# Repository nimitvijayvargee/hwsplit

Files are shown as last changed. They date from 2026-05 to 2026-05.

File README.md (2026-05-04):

# hwsplit
handwired split keyboard with spare parts!

I made this for fun, and it is in NO WAY a functioning keyboard layout you may want to use. The function row does not work, and the backtick/tilde are also not present. There are probably going to be hundreds of flaws.

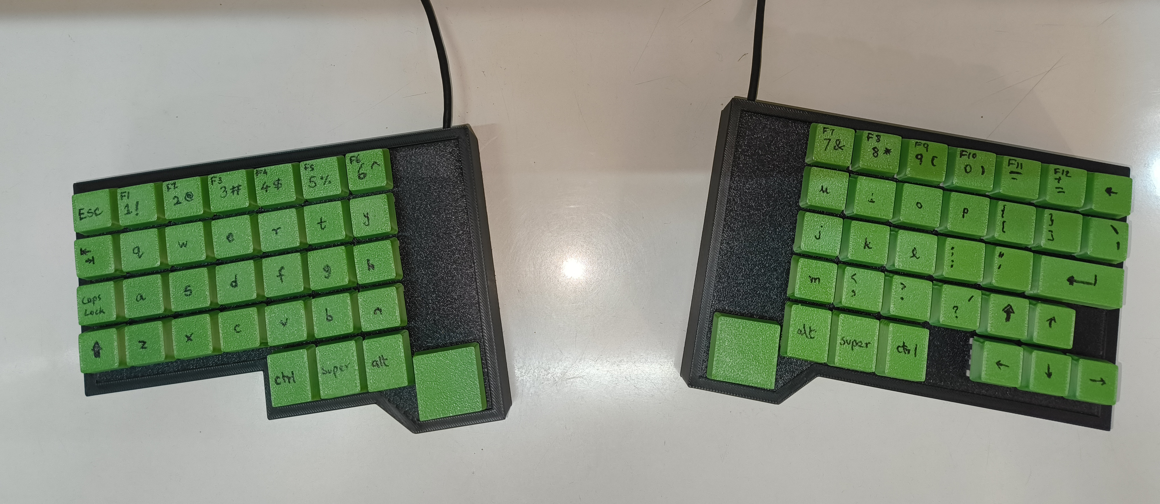
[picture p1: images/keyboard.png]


## Assembly Instructions
First of all, no idea why you'd EVER want to assembly one of these.
To begin, you must print the plates for both sides of the keyboard. I was able to do this in ~1.5 hours on my A1 in a single print. Pop your switches of choice through and wire up all the columns together. To make it easy, use solid core wire, enameled copper wire or a thin copper rod. Then, insulate the intersection points with the rows (I used masking tape) and connect the columns together. Make sure that the diodes point from the row to the switch (and subsequently to the column). Here's a sanity check for your matrix in KLE.
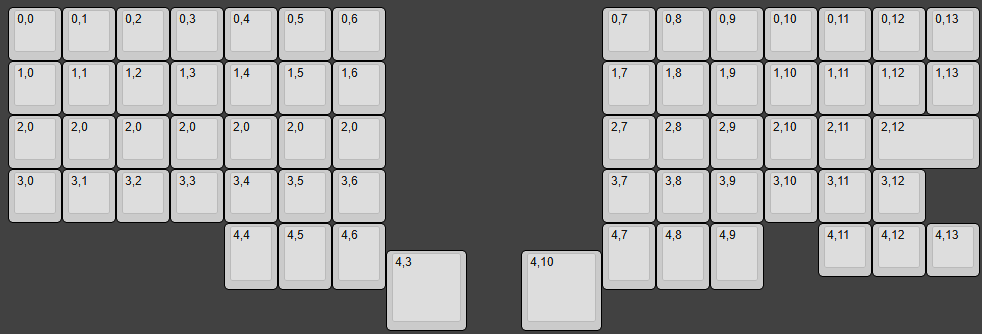
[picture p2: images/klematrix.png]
KLE matrix


Solder your wires to the Microcontroller (Pico). 

On the left:
  - Rows 0 to 4 -> GP0 to GP4
  - Columns 0 to 6 -> GP11 to GP5 (Backwards)

On the right:
  - Rows 0 to 4 -> GP0 to GP4
  - Columns 7 to 13 -> GP5 to GP11 (Forwards)

Flash your code by holding BOOTSEL on the pico while plugging it into your computer. Paste corresponding `.uf2` firmware files into the new `RPI-RP2` drive on your computer. Keyboard should automatically restart and start working.

Try using Vial's matrix tester to validate your matrix using the app (https://get.vial.today/) or on the web (https://vial.rocks/). Vial on the web needs a WebHID compatible browser. This includes almost all desktop versions of chromium (Edge, Arc, Chrome, etc.).

You can then set your keys to whatever you want!

If you need visual help, you may find some images in my [Journal](JOURNAL.md),
## Keycaps Needed
You will need 56x 1u keycaps, 1x 2u keycap and 6x 1.25u keycaps. The spacebar (or spaceblocks) are 2x (1.5u x 1.5u) square keycaps. These are not available anywhere to my knowledge. 

I printed all my keycaps, so it may be wise to do so.

## Overall BOM
- Soldering equipment (Iron, Solder and maybe flux)
- Solid Core copper wire / Thin Copper Rods / Enameled Copper Wire (Columns)
- Tape (any kind, I used masking/painter's tape)
- Switches (MX style, or anything that fits on an 19.05mm grid with 18mm cutouts).
- Diodes (1N4148)
- Case and Plate (I 3D printed these)
- 2x Raspberry Pi Picos
- 2x Micro USB-B Cables
- Keycaps (See above section)

Using switches from an old keyboard, the overall cost ran me about $13. I spent $5 on the wire, a little over $1 on the diodes and around $7 on the Picos.
Filament is not included in the cost, although I presume it did not take more than 500g of my daily PLA.

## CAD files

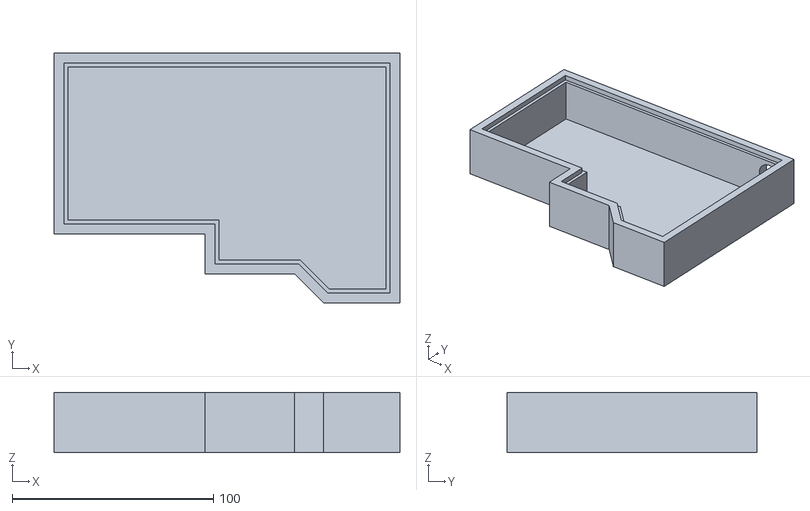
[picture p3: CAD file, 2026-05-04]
3dp/left_case.stl
172.1 x 124.3 x 30.0

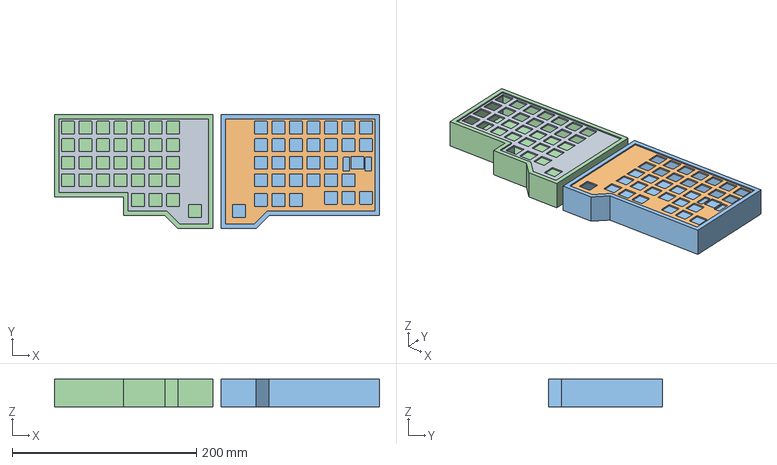
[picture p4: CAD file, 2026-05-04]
cad/hwsplit.step
352.9 x 124.3 x 30.0 mm

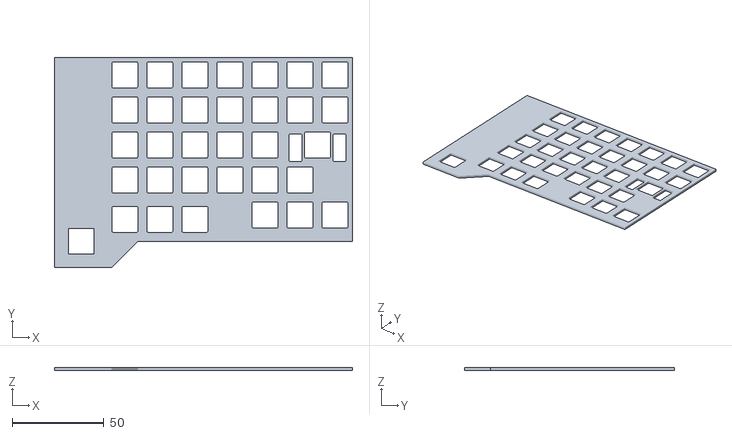
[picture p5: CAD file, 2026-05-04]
3dp/right_plate.stl
162.1 x 114.3 x 1.60

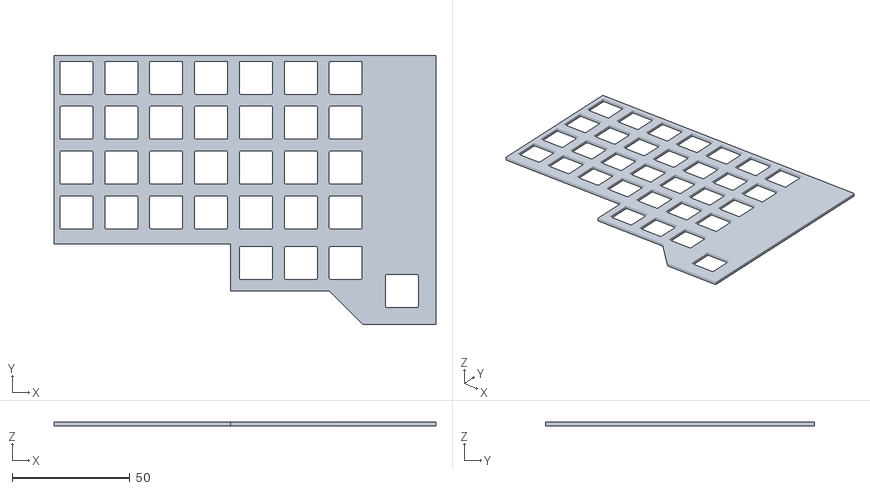
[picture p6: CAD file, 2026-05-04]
3dp/left_plate.stl
162.1 x 114.3 x 1.60

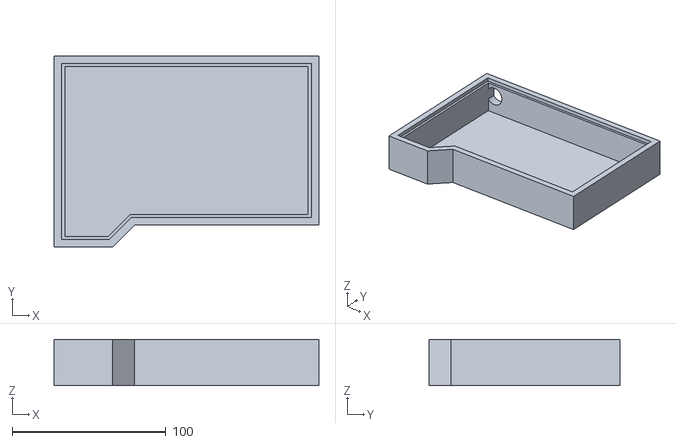
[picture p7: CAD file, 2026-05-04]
3dp/right_case.stl
172.1 x 124.3 x 30.0

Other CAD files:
cad/hwsplit.f3d

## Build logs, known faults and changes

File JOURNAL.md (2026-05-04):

# Journal
This is a journal log of all the work put into this project :) 
Use this while designing your keyboard if you want! Take everything with a mountain of salt, I messed up a lot of stuff

## Session 1
Time Spent: 45 Minutes

So I first started designing my keyboard using Keyboard Layout Editor. I took a bunch of inspiration from existing olkbs and split keyboards, and ended up on a decent looking layout! It had basically all I needed, and it looked quite straight forward. All the keycaps are readily available, except maybe the spacebars (which are actually 2 big 1.5u squares).
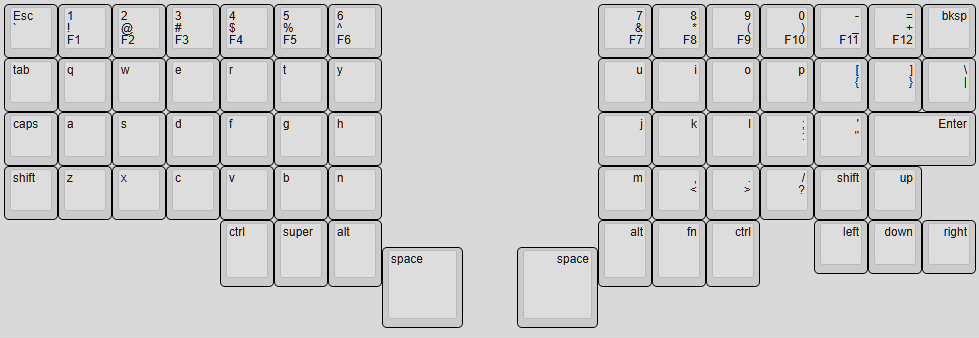
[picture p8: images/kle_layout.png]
KLE Layout


I moved the layout to ai03's Plate Generator tool (which is honestly such a good tool, wow); used the default settings and exported a DXF for my plate. I brought that plate into Fusion and extruded it 1.6mm and sent it to my printer. It's important that you make sure your printer can handle the dimensional accuracy. I used a 0.12mm layer height and a 0.4mm nozzle with mostly default settings on my Bambu Lab A1.
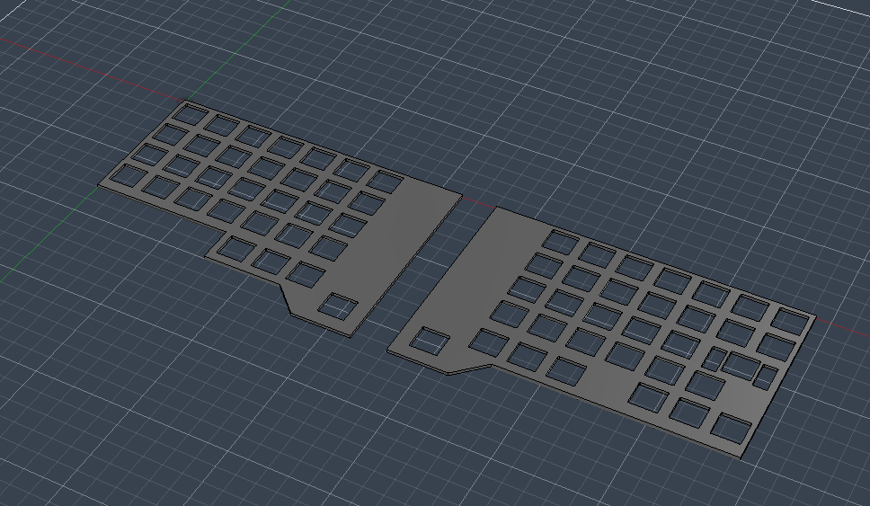
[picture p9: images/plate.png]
Plate

While the printer was printing, I also checked which parts I had and which parts I needed, and bought some diodes and solid core wire from an electronics store set to arrive on the same day.

## Session 2
Time Spent: 3 Hours

Around the time the plates finished printing, the parts also arrived! I used some spare switches from a 4 year old keyboard I had, and popped them into the plate where needed. I stripped the copper wires to solder the columns, and then insulated it with tape to solder diodes. It was really really shoddy on my first attempt. I also couldn't get the stabilizer in twt. Eventually, I finished soldering the first half and soldered some dupont connectors directly to the rows/columns quite easily. They did come off a lot, and my soldering could've been better.
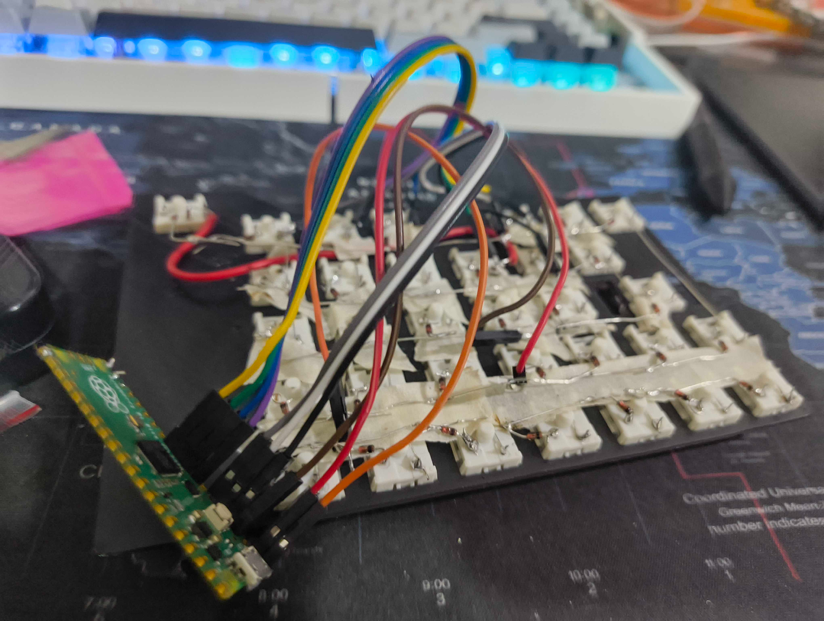
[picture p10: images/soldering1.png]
soldering 1


The thing with soldering for handwired keyboards is that it's extremely repepetive. It's easy to find yourself in a monotonous rhythym just as it is to find yourself in a flowstate.

After this, I took a small break and came back after 20 minutes to continue the other half.

## Session 3
Time Spent: 3 Hours

Armed with the new knowledge and skill on how to handwire keyboards, I started the left side of the keyboard!
I first added all of the columns, because that was the easy part. I added a small wire connecting to the space-square since it was quite straightforward.
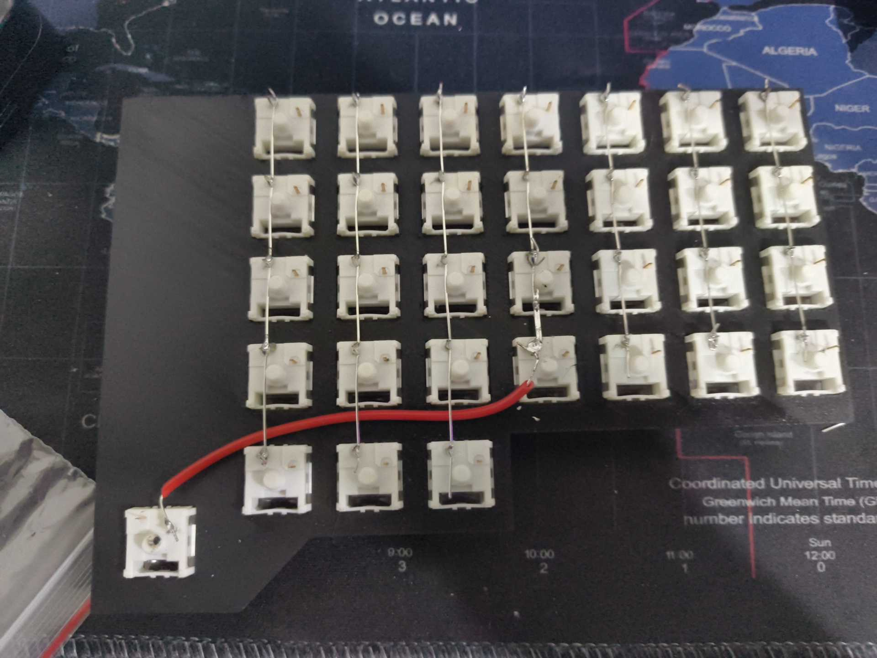
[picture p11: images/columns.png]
columns yay

After this, I added some tape to the parts between the switches to prevent shorting the columns and rows, and started soldering the diodes
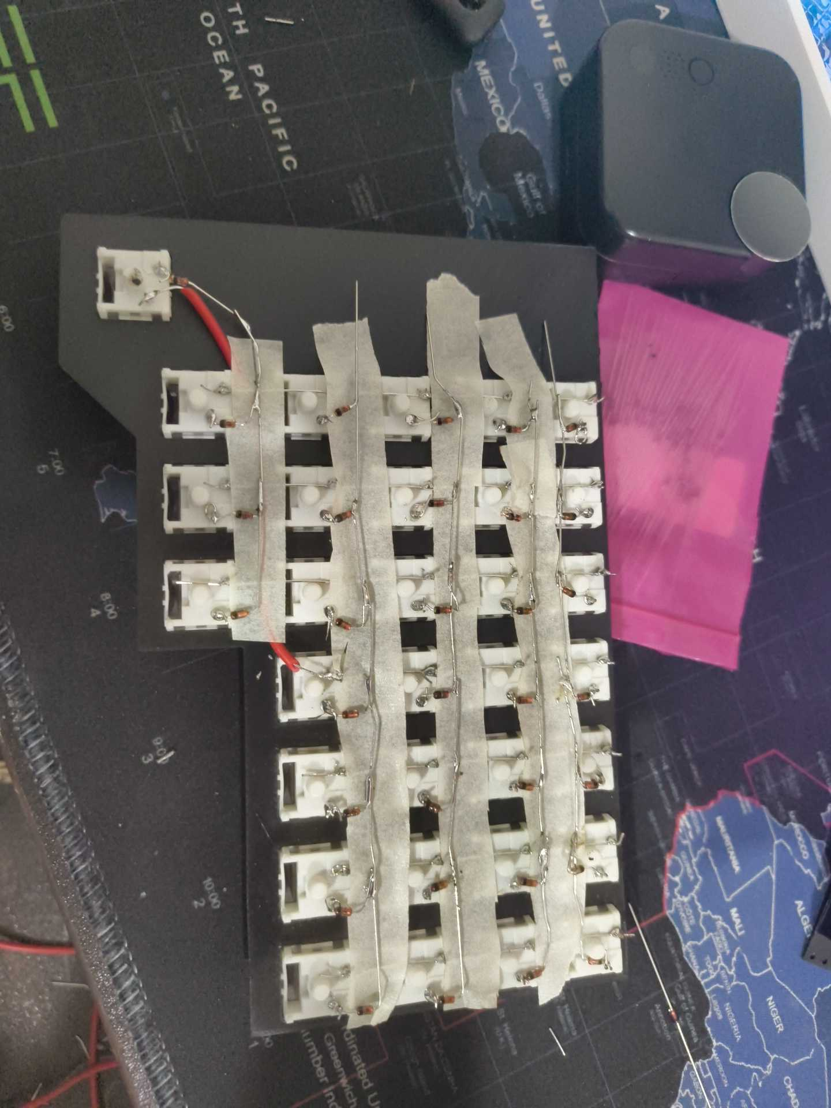
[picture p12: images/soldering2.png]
soldering 2

After finishing this thing, I quickly designed a small case and printed it. However, it wsa too shallow. I printed a deeper one and let that run overnight, and it kind of fit. But once I connected the USB cable, it didn't :(
Here's a picture of the case I printed in the morning!
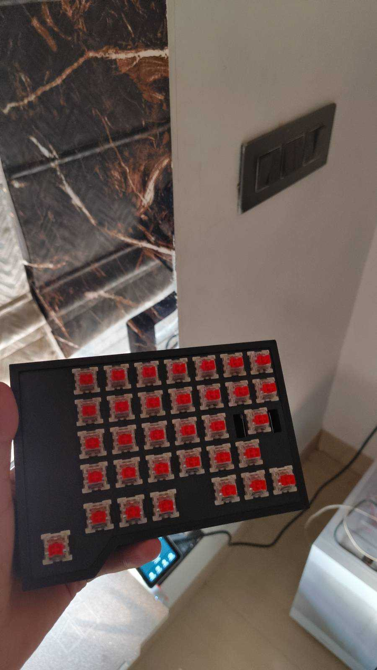
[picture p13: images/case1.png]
case


## Session 4
Time Spent: 2 Hours

I took the time to deepen out the cases 4mm more so that I have more headroom for the pico to be inside. I made a quick QMK firmware to see how it works, and spent the next hour reading docs and trying to find out how to do split keyboards that follow my mirrored matrix. I couldn't find that many resources, so I might just write my own code later, but I did somehow get it to show up in Vial?
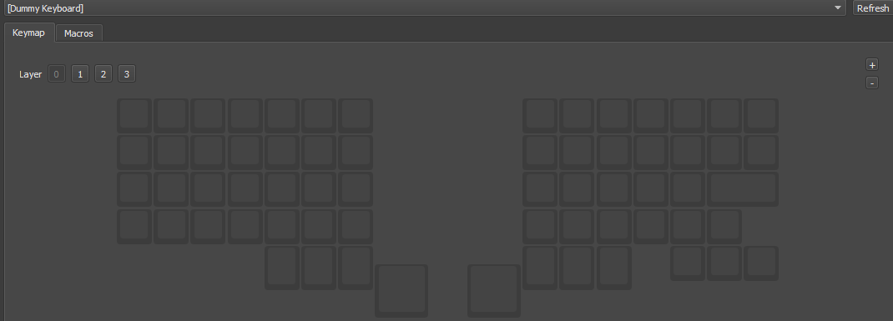
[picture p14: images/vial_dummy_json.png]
Vial Dummy JSON

Anyway I had spent too much time on QMK with no tangible results, so I took a break here.

## Session 5
Time Spent: 3 Hours

I came back and tried 2-3 times more to get QMK working, a few times without Vial included. I installed POG and KMK too, but that didn't work either. I thought that perhaps I had issues with the matrix, so I whipped up a quick matrix tester tool and that was going haywire on the right side but pretty chill on the left side so I KNOW my soldering was bad. I got enough spare switches to retry soldering the right side so I'll probably redo that.

## Session 6
Time Spent: 45 minutes

I quickly remodeled some old keycaps I had for a previous render and sent them off to the printer. After the plate finished printing for the right half I started attaching and soldering switches for that, but I need to desolder more switches from the previous attempt so I didn't complete it. After around 3 hours, all the keycaps finished printing and I am pretty proud of the result from that. Here's a picture!
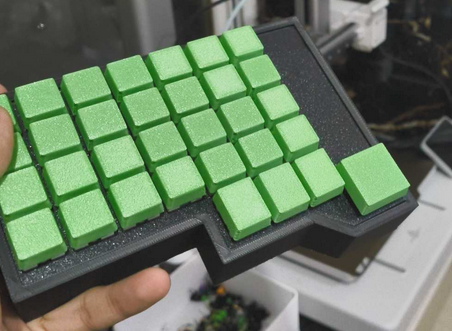
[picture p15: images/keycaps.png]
keycaps on


## Session 7
Time Spent: 2.5 Hours

I continued soldering the new plate for the right half, and this time it turned out significantly cleaner than my first attempt. I finished that half pretty easily, although each diode took 2 minutes to solder it manually :(
I attached the keycaps and soldered both the halfs together.
I flashed the previous matrix testing software and most of the keys worked fine except the first col and the second row, so I tried to resolder that.
I then continued working on the firmware.

## Session 8
Time Spent: 30 Minutes

I worked on some more firmware using some direct slave-master trickery but failed miserably many times. I don't think circuitpython is the solution, back to QMK it is.

## Session 9
Time Spent: 2 Hours

I decided that it's okay for my keyboard to have 2 USB cables if it means I get vial, so I quickly whipped up and compiled vial firmware and flashed it, and it worked like a charm! Matrix tester helped me debug some solder connections and I swiftly fixed those, and then assembled the cases once and for all.
Here's how it turned out!
keyboard final final(3).png

## Session 10
Time Spent: 30 Minutes

I completed the repository! I exported all the files and wrote the README to finally polish off this project :)

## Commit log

2026-05-04 Final Ship
    [left_case.stl, left_plate.stl, right_case.stl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]
2026-05-04 CAD files
    [hwsplit.f3d, hwsplit.step]
